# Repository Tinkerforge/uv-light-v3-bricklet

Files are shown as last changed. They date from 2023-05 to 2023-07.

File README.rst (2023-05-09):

UV Light Bricklet 3.0
=====================

This repository contains the firmware source code and the hardware design
files. The documentation generator configs can be found at
https://github.com/Tinkerforge/generators

Repository Content
------------------

software/:
 * examples/: Examples for all supported languages
 * build/: Compiled files
 * src/: Source code of firmware
 * Makefile: Makefile to build project

hardware/:
 * Contains KiCad project files and additionally schematics as PDF

datasheets/:
 * Contains datasheets for sensors and complex ICs that are used

Hardware
--------

The hardware is designed with the open source EDA Suite KiCad
(http://www.kicad.org). Before you are able to open the files,
you have to install the Tinkerforge kicad-libraries
(https://github.com/Tinkerforge/kicad-libraries). You can either clone
them directly in hardware/ or clone them in a separate folder and
symlink them into hardware/
(ln -s kicad_path/kicad-libraries project_path/hardware). After that you
can open the .pro file in hardware/ with KiCad and from there view and
modify the schematics and the PCB layout.

Software
--------

If you want to do your own Brick/Bricklet firmware development we highly
recommend that you use our build environment setup script and read the
tutorial (https://www.tinkerforge.com/en/doc/Tutorials/Tutorial_Build_Environment/Tutorial.html).

To compile the C code we recommend you to install the newest GNU Arm Embedded
Toolchain (https://launchpad.net/gcc-arm-embedded/+download).
You also need to install bricklib2 (https://github.com/Tinkerforge/bricklib2).

You can either clone it directly in software/src/ or clone it in a
separate folder and symlink it into software/src/
(ln -s bricklib_path/bricklib2 project_path/software/src/). Finally make sure to
have CMake installed (http://www.cmake.org/cmake/resources/software.html).

After that you can build the firmware by invoking make in software/.
The firmware (.zbin) can then be found in software/build/ and uploaded
with brickv (click button "Flashing" on start screen).

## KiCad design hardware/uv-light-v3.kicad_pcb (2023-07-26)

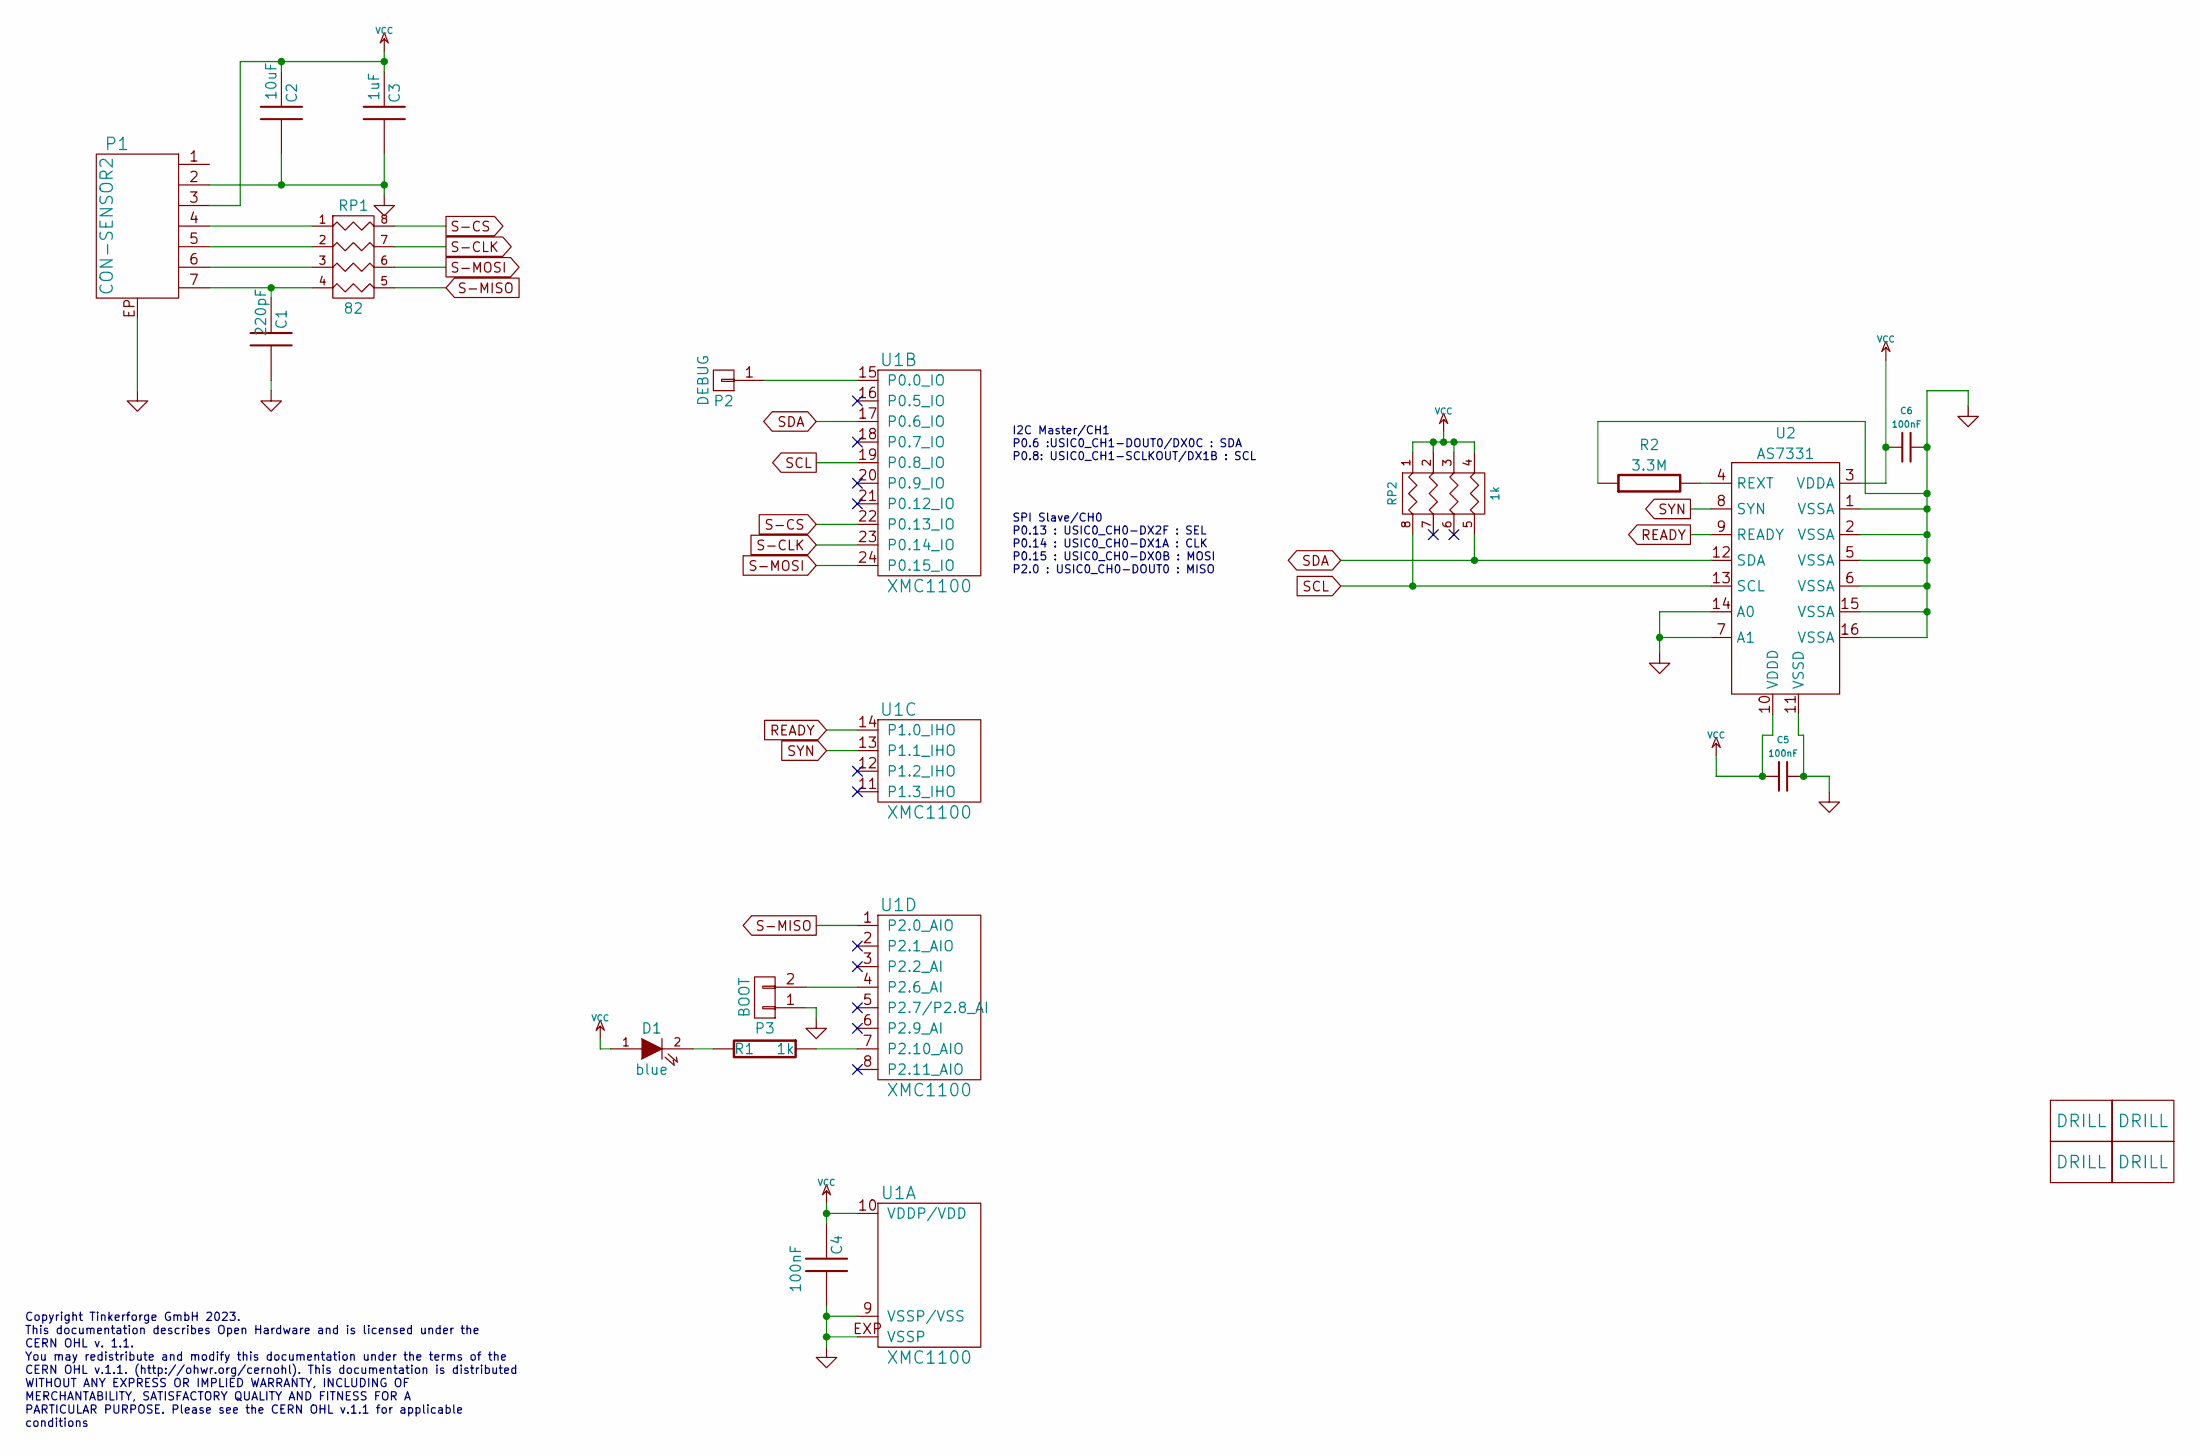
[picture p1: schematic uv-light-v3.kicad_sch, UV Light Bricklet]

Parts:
C1: 220pF; C0402F
C2: 10uF; C0805
C3: 1uF; C0603F
C4, C5, C6: 100nF; C0603F
D1: blue; D0603F
P1: CON-SENSOR2
P2: DEBUG; DEBUG_PAD
P3: BOOT; SolderJumper
R1: 1k; R0603F
R2: 3.3M; R0603F
RP1: 82; 4X0402
RP2: 1k; 0603X4
U1: XMC1100; QFN24-4x4mm-0.5mm
U2: AS7331
U3, U4, U5, U6: DRILL; DRILL_NP

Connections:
GND: C1.1, C2.1, C3.1, C4.1, C5.2, C6.2, P1.2, P1.EP, P3.1, R2.1, U1.9 (VSSP/VSS), U1.EXP (VSSP), U2.1 (VSSA), U2.2 (VSSA), U2.5 (VSSA), U2.6 (VSSA), U2.7 (A1), U2.11 (VSSD), U2.14 (A0), U2.15 (VSSA), U2.16 (VSSA)
unnamed: C1.2, P1.7, RP1.4
unnamed: D1.2 (K), R1.2
unnamed: P1.4, RP1.1
unnamed: P1.5, RP1.2
unnamed: P1.6, RP1.3
unnamed: P2.1, U1.15 (P0.0_IO)
unnamed: P3.2, U1.4 (P2.6_AI)
unnamed: R1.1, U1.7 (P2.10_AIO)
unnamed: R2.2, U2.4 (REXT)
READY: U1.14 (P1.0_IHO), U2.9 (READY)
S-CLK: RP1.7 (R2), U1.23 (P0.14_IO)
S-CS: RP1.8 (R1), U1.22 (P0.13_IO)
S-MISO: RP1.5 (R4), U1.1 (P2.0_AIO)
S-MOSI: RP1.6 (R3), U1.24 (P0.15_IO)
SCL: RP2.8 (R1), U1.19 (P0.8_IO), U2.13 (SCL)
SDA: RP2.5 (R4), U1.17 (P0.6_IO), U2.12 (SDA)
SYN: U1.13 (P1.1_IHO), U2.8 (SYN)
VCC: C2.2, C3.2, C4.2, C5.1, C6.1, D1.1 (A), P1.3, RP2.1, RP2.2, RP2.3, RP2.4, U1.10 (VDDP/VDD), U2.3 (VDDA), U2.10 (VDDD)

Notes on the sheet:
I2C Master/CH1 P0.6 :USIC0_CH1-DOUT0/DX0C : SDA P0.8: USIC0_CH1-SCLKOUT/DX1B : SCL
SPI Slave/CH0 P0.13 : USIC0_CH0-DX2F : SEL P0.14 : USIC0_CH0-DX1A : CLK P0.15 : USIC0_CH0-DX0B : MOSI P2.0 : USIC0_CH0-DOUT0 : MISO
Copyright Tinkerforge GmbH 2023. This documentation describes Open Hardware and is licensed under the CERN OHL v. 1.1. You may redistribute and modify this documentation under the terms of the CERN OHL v.1.1. (http://ohwr.org/cernohl). This documentation is distributed WITHOUT ANY EXPRESS OR IMPLIE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

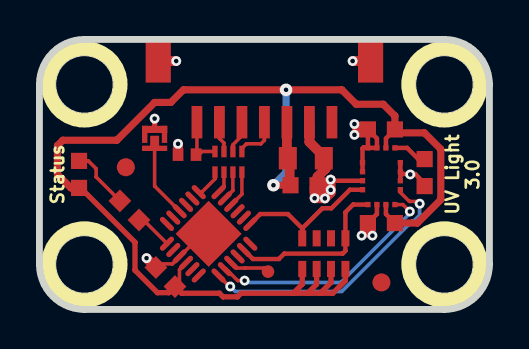
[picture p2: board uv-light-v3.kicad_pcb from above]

Board: 2 copper layers, 25.0 x 15.0 mm, 24 parts (2 on the bottom side), 19 nets.

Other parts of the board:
Fiducial_Mark: VAL**; Fiducial_Mark
Fiducial_Mark#2: VAL**; Fiducial_Mark
VAL: WEEE_7mm
VAL#2: CE_5mm

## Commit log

2023-05-09 schematic done
    [uv-light-v3.kicad_pcb, uv-light-v3.kicad_sch]
2023-05-10 first pcb layout
    [uv-light-v3.kicad_pcb, uv-light-v3.kicad_sch]
2023-05-10 ready for prototype
    [uv-light-v3.kicad_pcb, uv-light-v3.kicad_sch]
2023-07-26 changed mask layer to 0mm cutout, removed traces under AS7331
    [uv-light-v3.kicad_pcb]

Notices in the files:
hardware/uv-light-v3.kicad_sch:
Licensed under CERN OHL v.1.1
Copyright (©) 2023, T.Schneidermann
